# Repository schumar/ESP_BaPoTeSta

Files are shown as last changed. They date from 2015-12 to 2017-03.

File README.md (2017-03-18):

#  ESP8266 Battery Powered Temperature Station

## Moved to GitLab

This project has moved to [GitLab/schumar/ESP_BaPoTeSta](https://gitlab.com/schumar/ESP_BaPoTeSta)

## Intro

Using only an ESP8266 (no Atmel AVR) and a sensor, it's possible to build a very cheap and power-efficient WiFi-enabled weather station.

### Pictures of v0.3

BaPoTeSta Board v0.3 Rendering
BaPoTeSta Board v0.3 real

### Pictures of v0.5

BaPoTeSta Board v0.5 Rendering

### Pictures of v0.6

BaPoTeSta Board v0.6 Rendering
BaPoTeSta Board v0.6 with ATmega Rendering

### Maintenance Web-Interface

BaPoTeSta Webinterface

## Current state

I've already built 3 sensors of v0.3, and around 60 of v0.5.  
Right now I'm working on a major redesign of the board, and improving the firmware.

The sensors are reporting their data via MQTT, so the data can be received with [OpenHAB](http://www.openhab.org/),
[FHEM](http://fhem.de/fhem.html) or a small Perl script.

"Release early, release often" -- so don't expect to be able to clone this repo and have a working IoThingy 10 minutes later :)

## Screenshot

RRD Graph

## Technical details

-> Read the source, stare at my KiCAD schematic :)

## BOM

Quick calculation: 1 board would cost ca. 4.81 to 7.50 USD (excl. batteries),
depending on which sensors you want. (Calculation for an order of 30 boards)

Part|Need/Board|URL|per piece|per board
----|---------:|---|----------:|----------:|
PCB|1|http://dev.dangerousprototypes.com/store/pcbs|0.50|0.50
PinHdr|11|http://www.aliexpress.com/item/x/32537378399.html|0.01|0.09
1uF 1206|2|http://www.aliexpress.com/store/1361740|0.03|0.06
10uF|1|http://www.aliexpress.com/item/x/32260294384.html|0.07|0.07
ESP8266|1|http://www.aliexpress.com/item/x/32519328481.html|1.93|1.93
10k 1206|10|http://www.aliexpress.com/item/x/32569352008.html|0.01|0.09
56k 1206|1|http://www.aliexpress.com/item/x/32567865953.html|0.02|0.02
MCP1700|1|http://www.aliexpress.com/item/x/32523953207.html|0.36|0.36
BatteryCase|1|http://www.aliexpress.com/item/x/2022527017.html|1.06|1.06
**Sub-Total**||||**4.18**
DS18B20|1|http://www.aliexpress.com/item/x/32576213069.html|0.63|0.63
DHT22|1|http://www.aliexpress.com/item/x/32544057083.html|2.70|2.70
**Only DS18B20**||||**4.81**
**Only DHT22**||||**6.87**
**Both**||||**7.50**

## To Do

see [Issues](https://gitlab.com/schumar/ESP_BaPoTeSta/issues)

## Thanks

* Many thanks to all the people working on the [Arduino core for ESP8266](https://github.com/esp8266/Arduino)
* Cheers to [jdunmire](https://github.com/jdunmire/kicad-ESP8266) for his ESP8266 KiCAD library!

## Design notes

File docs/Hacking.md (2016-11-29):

# Hacking

## Install Arduino

Get Arduino from https://www.arduino.cc/en/Main/Software

## Add ESP8266 to Arduino

Start the Arduino IDE, go to File/Preferences, and add the following line to "Additional Boards Manager URLs:"
 http://arduino.esp8266.com/stable/package_esp8266com_index.json

Go to Tools/Board: "something"/Boards Manager...
Search for "esp82", click on the "esp8266 by ESP Community", click Install

(for details, see https://github.com/esp8266/Arduino)

## Add required libraries

In Sketch/Include Library, Manage Libraries...
Install "DallasTemperature", "DHT sensor library" and "PubSubClient".

## Clone this repository

cd ~/Arduino
git clone --recursive https://github.com/schumar/ESP_BaPoTeSta.git

## Start coding

Open the ESP_BaPoTeSta project in Arduino, and hack away

## Upload

### Connect a Serial-to-USB adapter to your board

Switch off your board.
Ensure that your adapter is set to 3.3V!
Connect the "GND" pin of the adapter to the "GND" pin of the ESP.
Connect the "TX" pin of the adapter to the "RX" pin of the ESP, and vice versa.
Do *not* connect VCC, unless you know what you are doing!

### Connect to your PC

I guess you can figure out how to do this :)

### Transfer firmware

Put a jumper bridge on the 2 "Upload" pins.
Press Ctrl+U in Arduino (or click the "Play" button)
While the sketch is compiling, switch on the board.

If it doesn't work the first time, make sure that the correct serial port is
selected in Tools/Port, and try again.

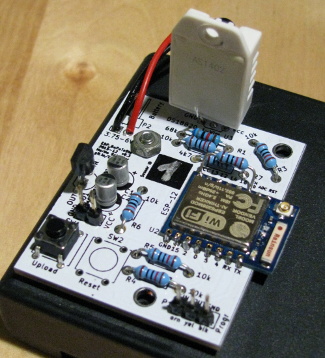
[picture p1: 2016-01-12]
docs/board_v0.3_real.jpg

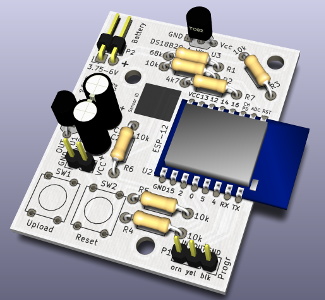
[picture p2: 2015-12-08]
docs/ESP_BaPoTeSta.jpg

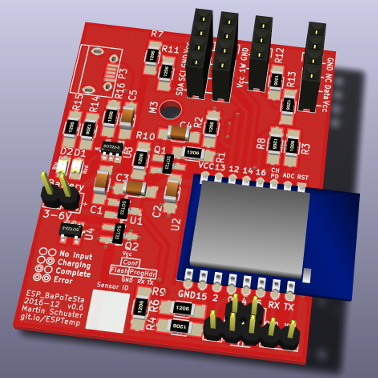
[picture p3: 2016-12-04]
docs/board_v0.6_render.jpg

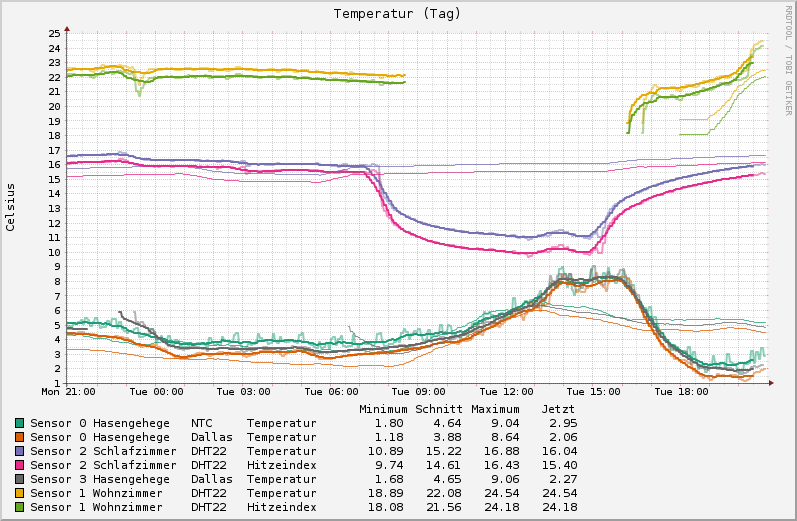
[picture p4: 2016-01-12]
docs/temp-daily.png

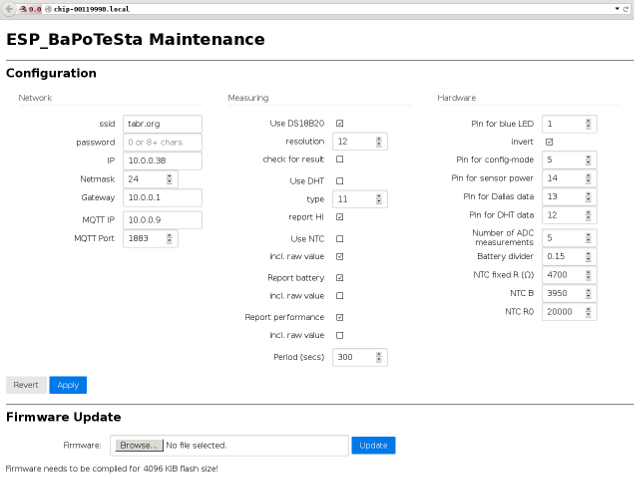
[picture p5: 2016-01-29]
docs/webinterface.png

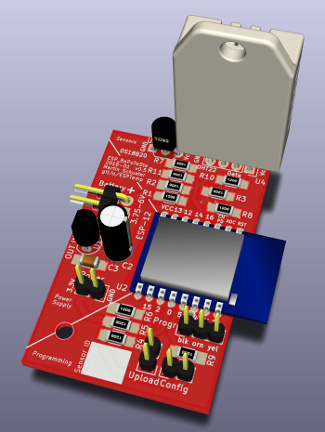
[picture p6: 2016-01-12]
docs/board_v0.5_render.jpg

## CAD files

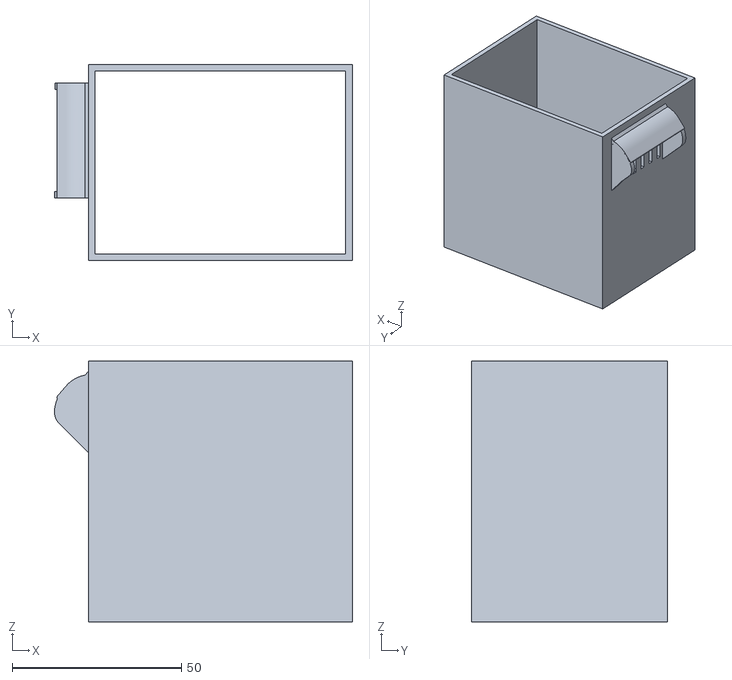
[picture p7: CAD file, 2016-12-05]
3d.printable.cases/outdoor.case/case-middle.stl
88.0 x 58.0 x 77.0

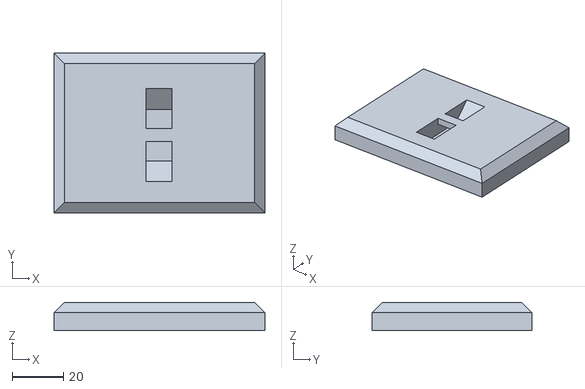
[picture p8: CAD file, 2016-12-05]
3d.printable.cases/outdoor.case/case_top.stl
82.0 x 62.0 x 11.0

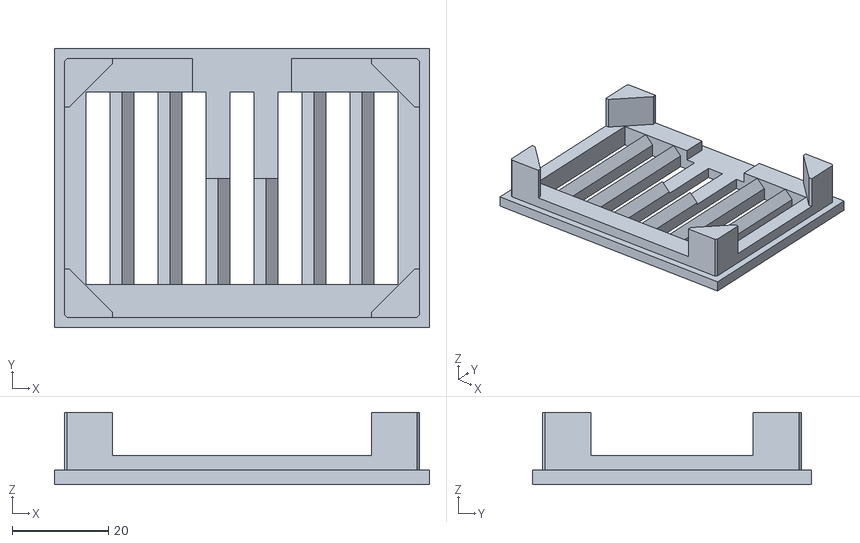
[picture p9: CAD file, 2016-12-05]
3d.printable.cases/outdoor.case/case_bottom.stl
78.0 x 58.0 x 15.0

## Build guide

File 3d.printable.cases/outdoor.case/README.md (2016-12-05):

#  3d printable Outdoor Case

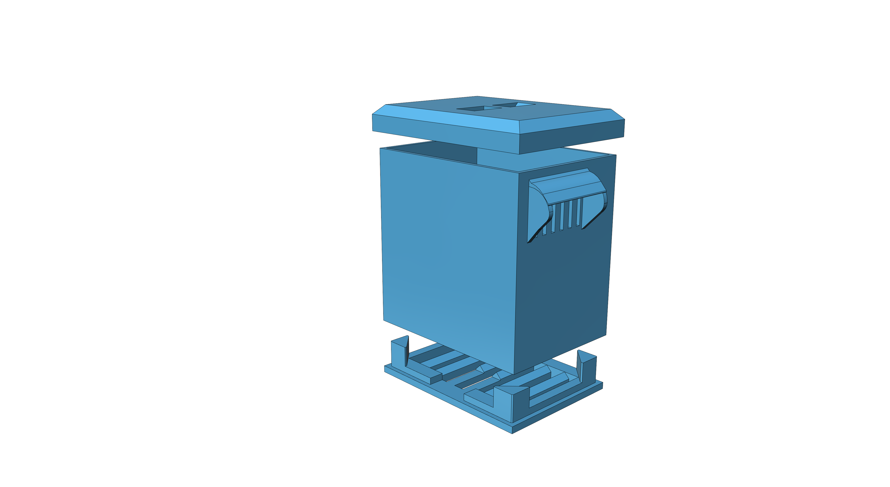
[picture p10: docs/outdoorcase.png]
Outdoor Case Rendering


Designed in 123D Design.

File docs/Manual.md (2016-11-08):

# Manual

## Read This First!

If you have acquired a finished BaPoTesTa, you can skip ahead to
(Configuration)[#configuration] now!

The following instructions are for the board as I designed it -- if you are
using another PCB, or have modified the schematics, they might still be a good
rough guideline.

If you want to attach other sensors, actuators, MOSFETs or whatever: There is
one unused pin (GPIO 4) which even has a through-hole you can solder a wire
into, and on the bottom of the board there are 2 solder bridges for GPIO 12
and GPIO 13 which you can cut to use those pins (originally for the DS18B20 and
DHT22, respecticely) too.

## Parts List

### Basic parts

* 1 PCB
* 10 SMD (1206) 10k&Omega; resistors
* 1 SMD (1206) 56k&Omega; resistor
* 2 SMD (1206) 1&mu;F capacitors
* 1 MCP1700 voltage regulator
* 1 100&mu;F buffer capacitor
* 1 ESP-12/12E/12F module
* 9 pin headers

### Power

You also need either either

* 1 case for 4 AA batteries
* 1 3mm screw+nut

or, if you want to plug in some other power source:

* 2 additional pin headers

### Sensors

One or both of
* 1 DS18B20 temperature sensor
* 1 DHT22 temperature&amp;humidity sensor

## Soldering

If you haven't done any soldering before (or your knowledge is a little rusty),
you might want to check the Internet for tutorials :) e.g.
* https://learn.sparkfun.com/tutorials/how-to-solder---through-hole-soldering
* https://learn.sparkfun.com/tutorials/how-to-solder---castellated-mounting-holes

but if you have some time, and want to have a good understanding of soldering,
check out
[PACE: Basic Soldering Lesson 1](https://www.youtube.com/watch?v=vIT4ra6Mo0s)  
(it's American, so prepare to snicker whenever the presenter pronounces
soldering as "soddering" :)

### Label your Board

Take a non water-solvable pen and write an ID on the white boxes on the front
and back of the board. Feel free to choose whatever scheme you want (most
people will go with "1, 2, 3,...", but why not use Klingon letters instead? ;)

### SMD Parts

Start with R1 (the only 56k&Omega; resistor, labelled "5602").  
Then do the 10k&Omega; resistors.

If you have a multi-meter, measure the resistance of R2, and the resistance
between the two left pins of R1 and R2 (R1+R2, as their right pins are
connected). Divide the first measurement (around 10k) by the second (around
66k), and note down the number (4 significant digits, i.e. "0.1534", not "0.15"
or "0.1533782")  
This will be the "battery divider" you can configure in the web-interface.

The only SMD parts left are the 2 1&mu;F capacitors (C1 and C3) -- add those.

Now is a good time to take some isopropanol, maybe mixed 1:1 with acetone,
and, using a brush, clean flux residue from the board (the ugly brown stuff).

### MCP 1700

That should be a no-brainer. Just make sure to put it in correctly (flat side
of the case points left/outward).

After soldering, cut off the 3 wires, and try to keep those short pieces, we'll
need them in the next step!

### ESP-12

I've found this to be a good way to solder the ESP-12:

* Tin the RST and GND pin of the PCB
* Put the module on the PCB
* Put 2 of the wires from the previous step through the little holes of the
  module, next to the VCC and TX pins (i.e. the corner pins which you *didn't*
  tin)
* Now heat the RST pin a little while pressing (gently!) down on the module.  
  This should fix that corner
* Do the same for GND
* Now the module is perfectly aligned and can't move anymore -- remove the 2
  wires.
* Solder all pins (do RST/GND last!)
* If you aren't an experiences solderer/ess(?), shortly heat each pin again
  (until the solder melts again), to ensure that all connections are flawless

But I'm just an amateur, so feel free to do it better! (and fork this project,
and improve this documentation ;)

This is again a good time to clean your board.

### Buffer Capacitor

This one should be easy again, just make sure that you don't swap the pins --
this is an electrolytic cap, so it has a plus- and a minus-pin, and swapping
those two can lead to Rapid Unplanned Disassembly.

### Pin Headers

Speaking from experience:
* Make sure that you count correctly! You need 3+2+2+2, and possibly 2 again
  for the power connection
* Those little bastards are really hard to separate! Using a good knife is the
  best way, but make sure not to cut yourself, and be aware that both parts will
  jump away the moment you separate them
* After soldering, those things are *hot* (d'uh). Touching them is bad
* Soldering might take a little more patience than usual, because the pins have
  a high thermal mass.

### Sensors

I've decided to use a "wide" footprint for the DS18B20, to make it easier to
solder in a cable instead of the sensor. But this means that if you want to put
the DS18B20 right on the board, you need to bend its pins a little bit. Tweezers
are quite useful for that.

While it's usually a good thing to keep pins as short as possible, I recommend
to keep the pins of the DS18B20 as *long* as possible, so the temperature
reading will be rather influenced by the air temperature than by the temperature
of the PCB.

When inserting the DHT22, make absolutely sure that the grill points outwards!

### Mounting Screw

Now is a good time to prepare a hole where the mounting screw will go through,
e.g. if you plan to put the board directly on a battery case, drill a hole
in that.

The antenna of the ESP-12 module (at the right border of the board) shouldn't
be covered by metal, if possible!

### Power

If you want to plug the power supply onto the board, solder in 2 pin headers.

Otherwise, solder the cables directly in the two pins. There are 2 small
mounting holes just left of the pins, which you can put the cables through (to
protect the solder joints from tension).

### Finish

Make one last visual inspection of all soldering joints.

If you want, you can switch on your board now -- it should briefly flash the
blue LED on the module. If the LED doesn't flash, switch off the board, take
your multimeter and test all connections :(  
If it does flash, switch the board off again; no use in wasting energy.

Tin, clean, re-tin you soldering iron, switch it off, clean the board, put back
any unused parts. Wash your hands if you aren't using lead-free solder!

Congratulations :)  
You are now ready to flash the firmware!

## Flashing

Right now, your ESP-12 has the stock firmware, which is useless for what we want
to do.

### Firmware

If you want to compile the firmware yourself, see the [Hacking doc](Hacking.md)
on how to do this.

But there are only a few reason to do so:

* Your ESP8266-module has a flash size other than 4MiB
* You have modified the board (or using a completely different one), and can't
  use GPIO 5 for entering the Maintenance mode
* While you can change the WiFi-password for the Maintenance mode directly in
  the Maintenance web-interface, the board will still start with the default
  password the first time. If you are worried about that, you are even more
  paranoid than me :)
* You don't trust binaries you haven't compiled yourself -- good for you!

Otherwise, just take the [precompiled firmware](../precompiled/).

### Connect a Serial-to-USB adapter to your board

You need a Serial-to-USB adapter with support for 3.3V levels instead
of 5V, e.g. [FTL232](XXX)

* Switch off your board.
* Ensure that your adapter is set to 3.3V!
* Connect the "GND" pin of the adapter to the "GND" pin of the ESP.
* Connect the "TX" pin of the adapter to the "RX" pin of the ESP, and vice versa.
  Do *not* connect VCC, unless you know what you are doing!

### Connect the adapter to your PC

I guess you can figure out how to do this :)

Check dmesg for the device name of the adapter (e.g. /dev/ttyUSB0)

### Transfer firmware

You will also need the [esptool](XXX), and of course 
* Put a jumper bridge on the 2 "Upload" pins.
* Type the command
  esptool -vv -cd ck -cb 115200 -cp /dev/ttyUSB0 -ca 0x00000 -cf ESP_BaPoTeSta.ino.bin
  but don't press enter yet
* Switch on the board
* Press Enter

If it doesn't work the first time, make sure that you have specified the correct
device name, and that you haven't swapped TX and RX. Try again.

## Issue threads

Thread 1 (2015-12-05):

[arduino] Add support for 1-wire sensors

schumar, 2015-12-05:
RIght now the code only supports an NTC as temperature-sensor.
Support 1-wire sensors (DS18B20, DHT11, DHT22,...) too

schumar, 2016-01-05:
DHT22 is not a 1Wire-device. ouch.
So commit:e0159d8 closes this issue.

Closed 2016-01-05.

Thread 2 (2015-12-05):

[arduino] add more power-saving measures

schumar, 2015-12-05:
* switch off UART
* put all unused pins into INPUT/OUTPUT/?
* (read ESP8266 data-sheet, search web)

schumar, 2016-01-09:
The current board needs around 500uA in sleep, that's half a year running on 2000mAh-batteries.
This is completely negligible compared to the ca. 100mA when the chip is "on".

Closed 2016-01-09.

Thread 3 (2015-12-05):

[arduino] timestamp values

schumar, 2015-12-05:
Right now, we only send a single value (temperature); add the current timestamp.

This needs NTP, and we don't want to do an NTP-query every time we wake up, so: EEPROM.

clever plan (taken from my comments in the source):
<pre>
        read time + counter from eprom
        if 0, or counter > 100(?)
            retrieve time via NTP
            reset counter
            write new time to eprom
        when sending data, use time + counter * (SLEEPSEC + c)
            c needs to be calibrated (few secs)
        write counter to eprom
</pre>

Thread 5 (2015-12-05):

[pcb] move "Values" to silk-screen

schumar, 2015-12-05:
Looks like I have to manually `s/F.Fab/F.SilkS/` in the pcb file, according to [this KiCAD forum post](https://forum.kicad.info/t/join-silkscreen-layers/1456/3), and the friendly guys on #kicad@freenode

Closed 2015-12-06.

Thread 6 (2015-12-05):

[pcb] add test points

schumar, 2015-12-05:
GND, VCC, 1Wire

schumar, 2016-01-09:
There's already a pin-header for Vcc/GND, everything else is easily accessible on the board :)

Closed 2016-01-09.

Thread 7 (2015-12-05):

[pcb] label ProgHdr

schumar, 2015-12-05:
Label the ProgHdr pins "RXI/Org" and "TXO/Red" (or was it the other way round? check first!), and "GND/blk"
BattHdr "+"/"-"
...

schumar, 2015-12-06:
fixed in commit/583a656

Closed 2015-12-06.

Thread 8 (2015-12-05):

[pcb] add BOM

schumar, 2015-12-05:
Add a nice BOM (maybe include it in the README), ideally with links to aliexpress or dx

schumar, 2015-12-06:
commit/583a656 fixes #7, not #8 *sigh*

Closed 2015-12-06.

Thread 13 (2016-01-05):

[arduino] support DHT22

schumar, 2016-01-05:
New issue, as #1 only handled 1-Wire sensors

Closed 2016-01-05.

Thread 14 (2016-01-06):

[pcb] MCP1700 pins wrong

schumar, 2016-01-06:
Pins of MCP1700 are GND-In-Out, not In-GND-Out

Closed 2016-01-09.

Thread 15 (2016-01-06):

[pcb] Reset-button attached to wrong pin

schumar, 2016-01-06:
For unknown reasons, I have attached the button "Reset" to GPIO15 instead of the RST pin

Closed 2016-01-09.

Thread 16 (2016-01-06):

[pcb] Wake-up doesn't work

schumar, 2016-01-06:
I've connected pin CH_PD instead of GPIO16 to RST

Closed 2016-01-09.

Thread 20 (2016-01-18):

[arduino] implement correction offset

schumar, 2016-01-18:
Allow user to specify an offset for each sensor/measurement, e.g. "-0.1" would mean "report 0.1 less than what the sensor measured".

schumar, 2016-04-20:
implemented in 1ab810149525a7f45dca42e1722ebf7dc1ef25d9

Closed 2016-04-20.

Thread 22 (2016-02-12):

[pcb] SMD-pins connected to GND-plane are hard to solder

schumar, 2016-02-12:

florianschmidt, 2016-02-19:
Sorry to say but I can't reproduce this. Also the GND-plane connected SMD-pins where easy to solder

Closed 2016-12-03.

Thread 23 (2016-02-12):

[pcb] make UART1 usable

schumar, 2016-02-12:
ESP8266 has a second UART, UART1, for debugging (TX-only, on GPIO2)
Think about some way of making it usable

schumar, 2016-12-03:
As GPIO2 is now "abused" for the data line of the DHT22, it is accessible already.

Closed 2016-12-03.

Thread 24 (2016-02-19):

100μF buffer capacitor to SMD?

florianschmidt, 2016-02-19:
Check possible SMD capacitors

mer-at, 2016-04-20:
those look quite cheap
http://tinyurl.com/jxrbo84

1206 SMD capacitor 100uf
50 pieces for 4,16$ including shipping

mer-at, 2016-04-20:
LP 2985 IM5-3,3 might be a good replacement for the voltage regulator?
1.0uA instead of 1.6uA standby current.
16V supply voltage instead of just 6V (4 normal AA Batteries already give me 6,57V)
reichelt got them for 47cent a piece

can be used with small ceramic capacitor as output cap.

schumar, 2016-04-22:
The LP2985 is only rated for 150mA; but LP38691DT-3.3 looks interesting

schumar, 2016-11-29:
Created #33 for the voltage regulator topic.

Closed 2016-11-30.

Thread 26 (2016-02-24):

[src] confg mode SSID/PW doesn't get set

schumar, 2016-02-24:
uses ESP_[sernr] as SSID, and no PW

schumar, 2016-04-20:
Looks like this was caused by a bad Arduino (IDE) setup, can't reproduce

Closed 2016-04-20.

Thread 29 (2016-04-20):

[pcb] avoid 90deg-corners

schumar, 2016-04-20:
We shouldn't use 90deg-bends in traces, [according to Pete](https://www.youtube.com/watch?v=NJKZZArjdg8)

Closed 2016-11-29.

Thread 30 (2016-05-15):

[pcb] Electrolytic buffer cap wastes energy

schumar, 2016-05-15:
Might have significant leak current.
Thanks @MalteP!

schumar, 2016-11-29:
Also see #24

Closed 2016-11-30.

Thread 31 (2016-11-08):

[pcb] check trace widths

schumar, 2016-11-08:
According to http://circuitcalculator.com/wordpress/2006/01/31/pcb-trace-width-calculator/
a 5mil-trace at 200mA will only heat up by 1degC, and lose 19mV/inch

schumar, 2016-12-04:
"Saturn PCB Design Toolkit" https://www.saturnpcb.com/pcb_toolkit.htm
agrees, as does http://www.desmith.net/NMdS/Electronics/TraceWidth.html

Closed 2016-12-04.

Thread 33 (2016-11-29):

Investigate other voltage regulators

schumar, 2016-11-29:
People might want to use higher or lower input voltages.

LP38691DT-3.3 might be a good candidate (up to 10V, and dropout of only .25V, this would allow a range of 2.75-10V instead of the 3-6V we need now). 55uA quiescent current is quite high, though.

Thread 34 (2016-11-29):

Support replacing the ESP12 with an ATmega

schumar, 2016-11-29:
It should be possible to add the footprint of an ATmega328P-AU (TQFP, 7x7mm, 0.8mm pitch) within the ESP12-footprint.

random thoughts:
* lower standby current (0.9uA in "powersave" mode of AVR)
* no WiFi anymore
* ...so additional pins for controlling some 433MHz-thingy needed
* code needs to be able to handle both ICs
* "config" only via flashing new firmware
* traces below the ESP might act as little antennas
* could use internal oscillator, I2C/1Wire/DHT should be able to handle slight timing variations

schumar, 2016-12-04:
For the 433MHz-communication, use the RadioHead library,
http://www.airspayce.com/mikem/arduino/RadioHead/index.html

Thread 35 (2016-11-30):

[pcb] reverse leakage of battery charger?

schumar, 2016-11-30:
If no voltage is supplied via USB, will there be leakage current from the battery through the charger IC?
If so, this needs to be blocked (via MOSFET)

schumar, 2016-12-03:
0.25uA for floating Vdd according to datasheet, safe to ignore

Closed 2016-12-03.

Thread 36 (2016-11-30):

[pcb] Protect battery against under-voltage

schumar, 2016-11-30:
Right now, we will drain the poor battery until it's dead :cry:

schumar, 2016-11-30:
Of course, users can still use a battery which contains a protection-PCB, but that sounds like a waste of money

schumar, 2016-12-01:
Replacing the current charge controller with an MCP73871 would help (that chip sounds great), but it only comes in a QFN20 package, which is really tricky to solder by hand

schumar, 2016-12-03:
Switch a MOSFET through an undervoltage sensor like
http://www.onsemi.com/pub/Collateral/NCP300-D.PDF
?

Closed 2016-12-03.

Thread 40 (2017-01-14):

[pcb] on/off-switch

schumar, 2017-01-14:
...so the user can stop measuring while charging the battery (that will most likely happen at another place than the usual measurements, and thus introduce useless data)

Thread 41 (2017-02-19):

[pcb] MCP1700 wrong pinout

schumar, 2017-02-19:
The currently used pin-out (1=GND, 2=In, 3=Out) is only correct for the TO-92 and SOT-89 packages of this chip; the SOT-23 version has 1=GND, 2=Out, 3=In

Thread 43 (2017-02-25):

[pcb] battery measurement doesn't work

schumar, 2017-02-25:
I've used Malte's circuit with the MOSFET, completely ignoring the fact that he uses LOW to switch it on, while my setup sets PwrSens to HIGH while measuring :(

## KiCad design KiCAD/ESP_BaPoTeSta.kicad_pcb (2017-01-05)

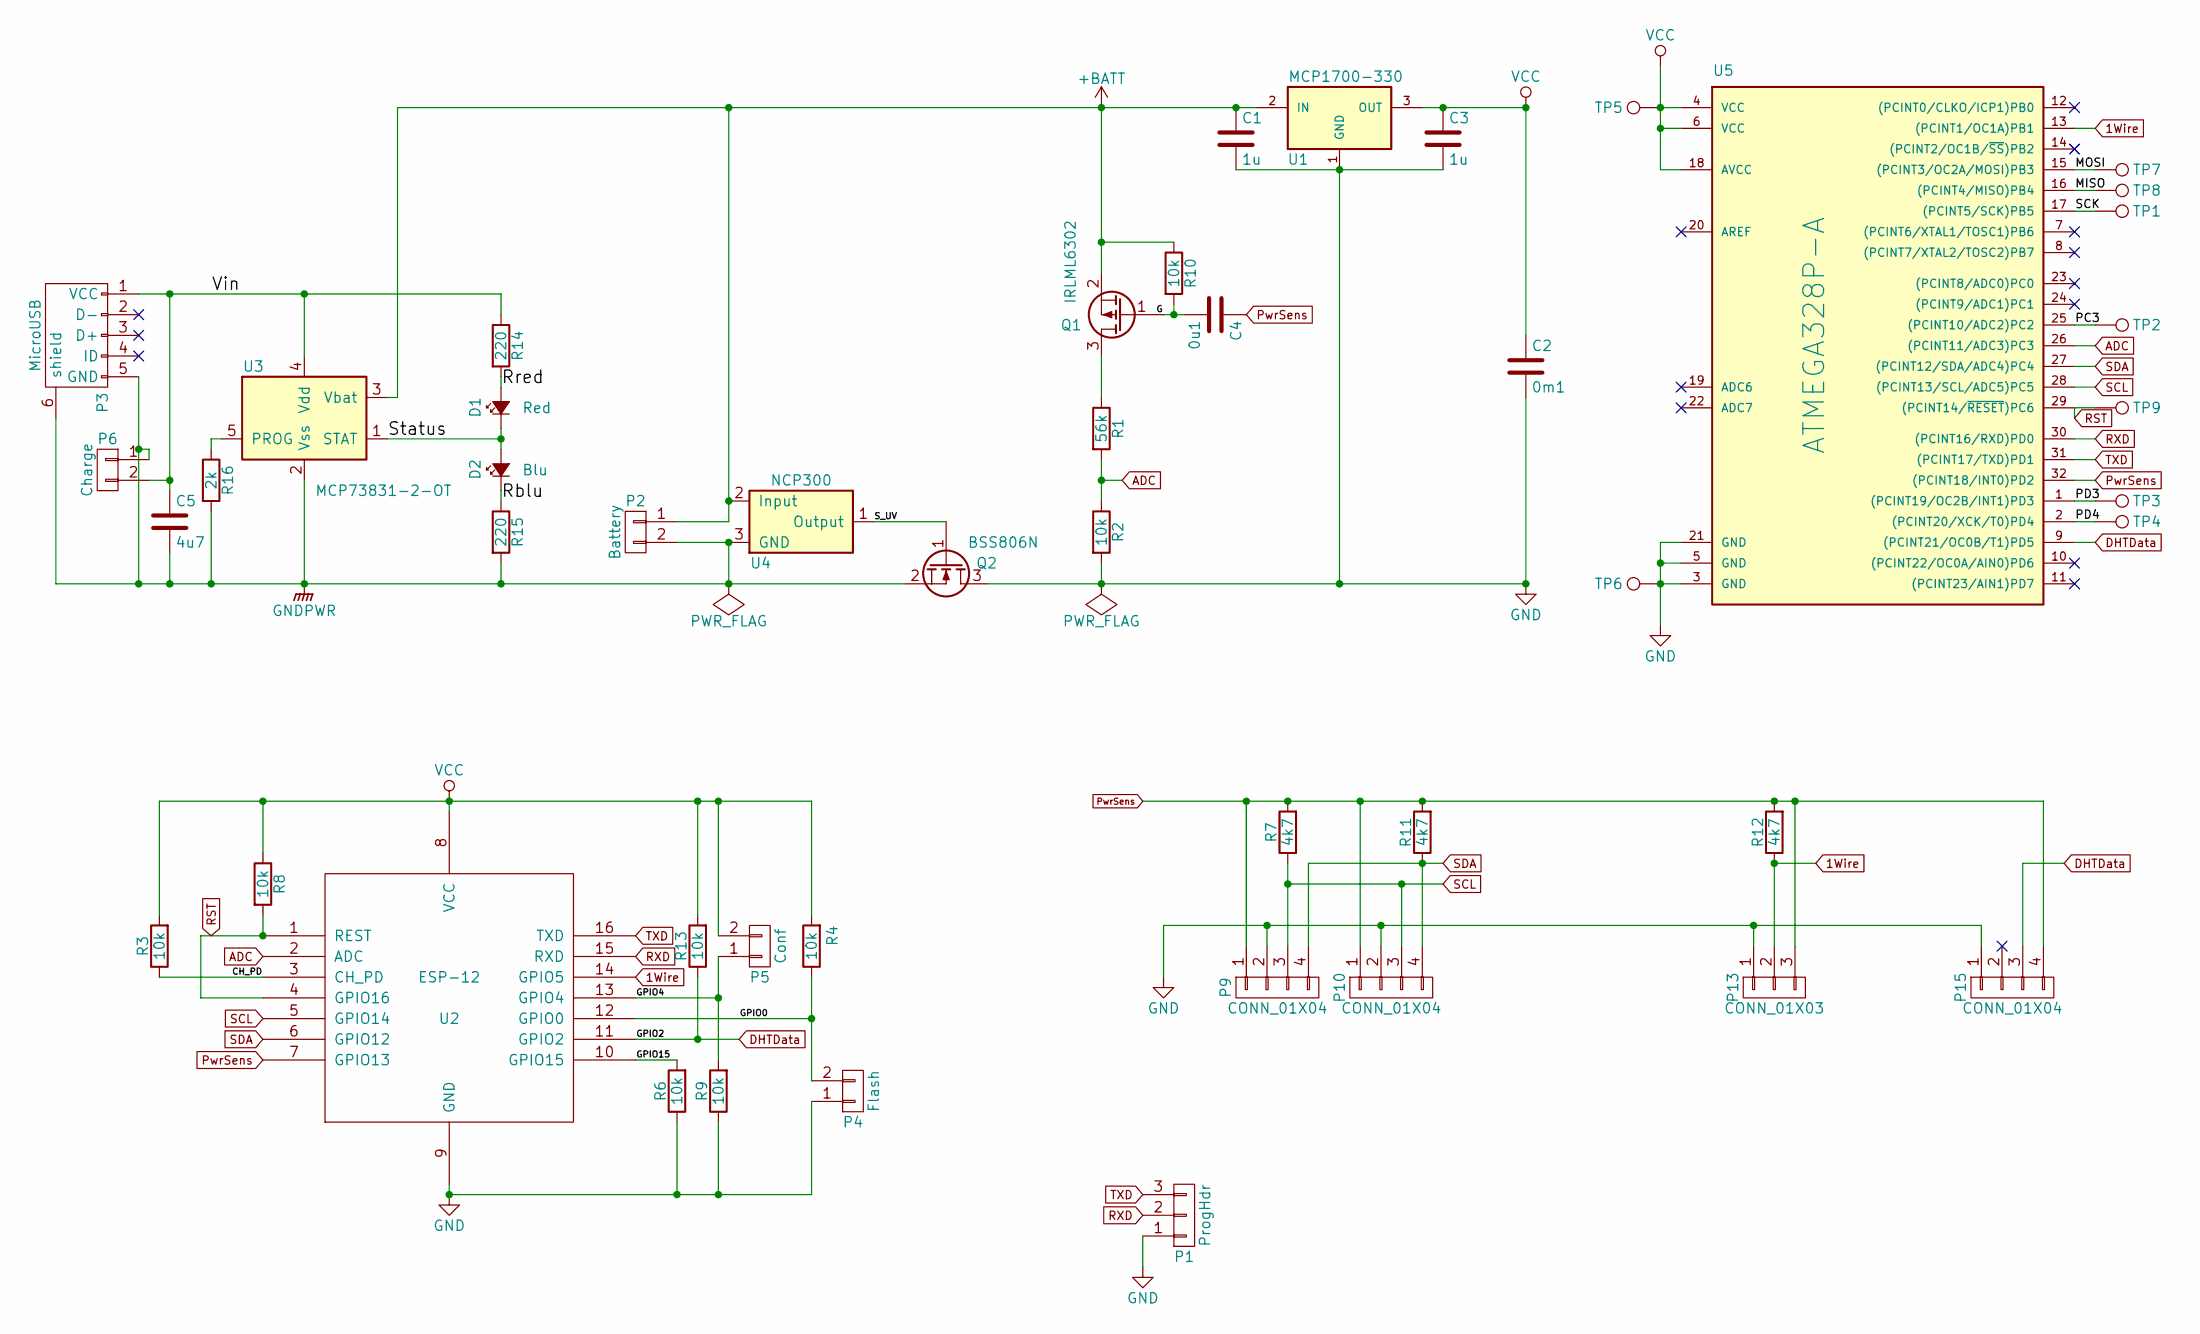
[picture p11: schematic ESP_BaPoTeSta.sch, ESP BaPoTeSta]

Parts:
C1, C3: 1u; C_1206_HandSoldering
C2: 0m1; C_1206_HandSoldering
C4: 0u1; C_1206_HandSoldering
C5: 4u7; C_1206_HandSoldering
D1: Red; LED_0805
D2: Blu; LED_0805
P1: ProgHdr; Pin_Header_Straight_1x03
P2: Battery; Pin_Header_Straight_1x02
P3: MicroUSB; USB_Micro-B
P4: Flash; Pin_Header_Straight_1x02
P5: Conf; Pin_Header_Straight_1x02
P6: Charge; Pin_Header_Straight_1x02
P9, P10, P15: CONN_01X04; Socket_Strip_Straight_1x04
P13: CONN_01X03; Socket_Strip_Straight_1x03
Q1: IRLML6302; SOT-23_Handsoldering
Q2: BSS806N; SOT-23_Handsoldering
R1: 56k; R_1206_HandSoldering
R2, R3, R4, R6, R8, R9, R10, R13: 10k; R_1206_HandSoldering
R7, R11, R12: 4k7; R_1206_HandSoldering
R14, R15: 220; R_1206_HandSoldering
R16: 2k; R_1206_HandSoldering
TP1, TP2, TP3, TP4, TP5, TP6, TP7, TP9: TEST_1P; Measurement_Point_Square-SMD-Pad_Small
TP8: TEST_1P; Measurement_Point_Round-SMD-Pad_Small
U1: MCP1700-330; SOT-23_Handsoldering
U2: ESP-12
U3: MCP73831-2-OT; SOT-23-5
U4: NCP300; SOT-23-5
U5: ATMEGA328P-A; TQFP-32_7x7mm_Pitch0.8mm

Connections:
1Wire: P13.2, R12.1, U2.14 (GPIO5), U5.13 ((PCINT1/OC1A)PB1)
+BATT: C1.1, P2.1, Q1.2 (S), R10.1, U1.2 (IN), U3.3 (Vbat), U4.2 (Input)
/CH_PD: R3.1, U2.3 (CH_PD)
/G: C4.2, Q1.1 (G), R10.2
/GPIO0: P4.2, R4.1, U2.12 (GPIO0)
/GPIO4: P5.1, R9.2, U2.13 (GPIO4)
/GPIO15: R6.2, U2.10 (GPIO15)
/MISO: TP8.1, U5.16 ((PCINT4/MISO)PB4)
/MOSI: TP7.1, U5.15 ((PCINT3/OC2A/MOSI)PB3)
/PC3: TP2.1, U5.25 ((PCINT10/ADC2)PC2)
/PD3: TP3.1, U5.1 ((PCINT19/OC2B/INT1)PD3)
/Rblu: D2.1 (K), R15.1
/Rred: D1.2 (A), R14.2
/SCK: TP1.1, U5.17 ((PCINT5/SCK)PB5)
/S_UV: Q2.1 (G), U4.1 (Output)
/Status: D1.1 (K), D2.2 (A), U3.1 (STAT)
/Vin: C5.1, P3.1 (VCC), P6.2, R14.1, U3.4 (Vdd)
ADC: R1.2, R2.1, U2.2 (ADC), U5.26 ((PCINT11/ADC3)PC3)
DHTData: P15.3, R13.1, U2.11 (GPIO2), U5.9 ((PCINT21/OC0B/T1)PD5)
GNDPWR: C5.2, P2.2, P3.5 (GND), P3.6 (shield), P6.1, Q2.2 (S), R15.2, R16.2, U3.2 (Vss), U4.3 (GND)
unnamed: Q1.3 (D), R1.1
unnamed: R16.1, U3.5 (PROG)
PwrSens: C4.1, P9.1, P10.1, P13.3, P15.4, R7.2, R11.2, R12.2, U2.7 (GPIO13), U5.32 ((PCINT18/INT0)PD2)
RST: R8.2, TP9.1, U2.1 (REST), U2.4 (GPIO16), U5.29 ((PCINT14/~RESET~)PC6)
RXD: P1.2, U2.15 (RXD), U5.30 ((PCINT16/RXD)PD0)
SCL: P9.3, P10.3, R7.1, U2.5 (GPIO14), U5.28 ((PCINT13/SCL/ADC5)PC5)
SDA: P9.4, P10.4, R11.1, U2.6 (GPIO12), U5.27 ((PCINT12/SDA/ADC4)PC4)
TXD: P1.3, U2.16 (TXD), U5.31 ((PCINT17/TXD)PD1)
VCC: C2.1, C3.1, P5.2, R3.2, R4.2, R8.1, R13.2, TP5.1, U1.3 (OUT), U2.8 (VCC), U5.4 (VCC), U5.6 (VCC), U5.18 (AVCC)

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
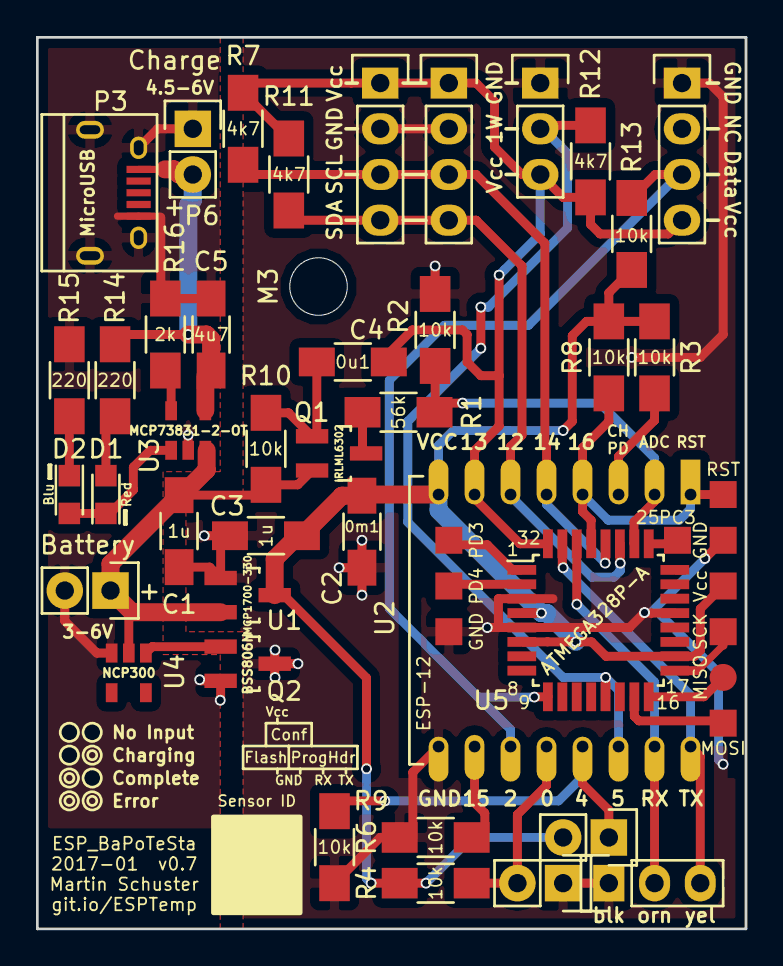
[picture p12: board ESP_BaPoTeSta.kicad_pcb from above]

Board: 2 copper layers, 39.4 x 49.5 mm, 50 parts (0 on the bottom side), 31 nets.

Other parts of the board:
M3: MountingHole_3.2mm_M3_ISO7380
TP4#2: TEST_1P; Measurement_Point_Square-SMD-Pad_Small

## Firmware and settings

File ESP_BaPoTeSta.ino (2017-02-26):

/*
   ESP8266 Battery Powered Temperature Station
   https://git.io/ESPTemp

   Martin Schuster 2015 - 2016
 */

#include <ESP8266WiFi.h>
#include <WiFiUdp.h>
#include <math.h>
#include <OneWire.h>
#include <DallasTemperature.h>
#include <DHT.h>
#include <PubSubClient.h>
#include <ESP8266WebServer.h>
#include <ESP8266mDNS.h>
#include <ESP8266HTTPUpdateServer.h>
#include <EEPROM.h>
#include <Wire.h>
#include <Adafruit_Sensor.h>
#include <Adafruit_BMP280.h>

#ifdef SERIALDEBUG
#include <Serial.h>
#endif

#include "config.h"
#include "ESP_BaPoTeSta.h"

// globals
struct sensorMeasurement sensorMeasurements[maxSensors];
struct allMeasurements data;
struct config config;
WiFiClient espClient;
PubSubClient mqttClient(espClient);
OneWire oneWire(0xff);
DallasTemperature dallasSensors(&oneWire);
DHT dhtSensor(0,0);
bool configmode = false;
ESP8266WebServer httpServer(80);
IPAddress IPSubnet(255, 255, 255, 0);

Adafruit_BMP280 bmp280;

#ifdef SERIALDEBUG
ESP8266HTTPUpdateServer httpUpdater(true);
#else
ESP8266HTTPUpdateServer httpUpdater;
#endif


void setup() {
    // activate (active low) blue LED to show that we are "on"
    if (config.pinblue >= 0) {
        pinMode(config.pinblue, OUTPUT);
        digitalWrite(config.pinblue, config.invblue ? LOW : HIGH);
    }

    #ifdef SERIALDEBUG
    Serial.begin(230400);
    delay(10);
    debugPrint("\nSYNCSYNC\n");
    #endif

    EEPROM.begin(1024);
    getConfig();

    // check if "config mode" jumper is set
    if (digitalRead(config.pinconfig)) {
        debugPrint("Starting webserver");

        configmode = true;
        setupWebserver();

    } else {
        debugPrint("Starting normally");

        configmode = false;
        setupNormal();
    }
}

void setupNormal() {
    char idBuffer[32];

    // start WiFi
    debugPrint("Connecting to WiFi...");
    WiFi.mode(WIFI_STA);
    WiFi.config(config.ip, config.gw, IPSubnet);
    if (config.password == NULL || config.password[0] == 0) {
        WiFi.begin(config.ssid);
    } else {
        WiFi.begin(config.ssid, config.password);
    }

    // now is a perfect time for "other" stuff, as WiFi will need some time
    // to associate

    // get ChipID, will be used as unique ID when sending data
    data.chipId = ESP.getChipId();
    data.sensorMeasurements = sensorMeasurements;
    data.nrMeasurements = 0;

    if (config.battery) getBattery();

    powerSensors(true);     // activate power to sensors

    // setup Dallas sensors
    if (config.usedallas) {
        oneWire = OneWire(config.pindallas);
        dallasSensors.begin();
        dallasSensors.setResolution(config.dallasres);
        dallasSensors.setCheckForConversion(config.dallaswait);
    }

    // setup DHT sensor
    if (config.usedht) {
        dhtSensor = DHT(config.pindhtdata, config.dhttype);
        dhtSensor.begin();
    }

    // setup I2C
    if (config.usebmp280) {
        Wire.begin(config.pini2csda, config.pini2cscl);
    }

    // setup BMP280
    if (config.usebmp280) {
        // if bmp280addr is set, use it, otherwise stick to the default (0x77)
        if (! (config.bmp280addr > 0 ?
                    bmp280.begin(config.bmp280addr) : bmp280.begin())) {
            debugPrint("BMP280 not found.");
        }
    }

    // wait until WiFi is connected, but max maxConnRetry
    for (byte i = 0;
            i < maxConnRetry && WiFi.status() != WL_CONNECTED;
            i++)
        delay(sleepWifiCheck);
    // if this didn't work, go back to sleep
    if (WiFi.status() != WL_CONNECTED)
        gotoSleep(noConnSleepSec);

    debugPrint("Connected to WiFi.");

    // connect to MQTT server
    mqttClient.setServer(config.mqttip, config.mqttport);
    sprintf(idBuffer, "esp8266-%08lx", data.chipId);
    mqttClient.connect(idBuffer);
    debugPrint("Connected to MQTT server.");

}


void loop() {
    if (configmode) {
        httpServer.handleClient();
        delay(1);
    } else {
        // this won't actually "loop", as the last command leads to a reset
        data.timestep = 0;      // [XXX] this needs to be read from eprom and ++

        mqttClient.loop();

        collectData();          // make measurements
        powerSensors(false);    // deactivate power to sensors again

        sendData();
        mqttClient.loop();

        // wait a little bit, to ensure that everything is sent
        delay(sleepEnd);
        mqttClient.loop();
        gotoSleep(config.deltat);
    }
}

void collectData() {
    debugPrint("Collecting data...");
    if (config.usedallas) getDallas();
    if (config.usebmp280) getBMP280();
    if (config.usedht) getDHT();
    if (config.dowifi) getWiFi();
    if (config.doperf) getPerf();
}

void getDallas() {
    uint8_t addr[8];
    float temp;
    uint16_t id;

    debugPrint("Searching for DS18B20");

    // try to find address of first sensor
    if (dallasSensors.getAddress(addr, 0) == 0) return;

    dallasSensors.requestTemperaturesByAddress(addr);
    temp = dallasSensors.getTempC(addr);

    debugPrint("DSTmp=" + (String)temp);

    // sanity check; valid range taken from datasheet
    // "85" is the "reset value", ignore it too
    if (temp < -55.0 || temp > 125.0 || (temp > 84.95 && temp < 85.05))
        return;

    // add the bias after checking for "85" above
    temp += config.biasDallasTemp;

    if (DALLAS_ID > 0) {
        id = DALLAS_ID;
    } else {
        id = (addr[2]<<8) + addr[1];
    }

    // use last two byte of serial as ID (addr[0] is "family code")
    addData(id, TEMP, (int) (temp * 100.0), CENT_DEGC);
}

void getBMP280() {
    float temp;
    float pres;

    debugPrint("Querying BMP280...");

    temp = bmp280.readTemperature();
    pres = bmp280.readPressure();

    debugPrint("BMP280Temp=" + (String)temp + "\n" +
               "BMP280Pres=" + (String)pres);

    if (pres < 1.0)
        return;

    addData(0x0280, TEMP, (int) (temp * 100.0), CENT_DEGC);

    if (config.bmppress) {
        // report measured pressure (current height)
        addData(0x0280, PRESSURE, (int) (pres), PASCAL);
    }
    if (config.bmpslp && config.heightASL > 0) {
        // report pressure at sea level
        addData(0x0280, PRESSUREASL, (int) (sealevelPressure(pres)), PASCAL);
    }
}

void getDHT() {
    delay(sleepDHT);    // [XXX] should substract the time since power-up

    // store values, so they can be used for calculating the heat index later
    float temp = dhtSensor.readTemperature(false, true) + config.biasDHTTemp;
    float hum = dhtSensor.readHumidity() + config.biasDHTHumid;

    debugPrint("DHTHum=" + (String)hum);
    debugPrint("DHTTmp=" + (String)temp);
    // sanity check; valid range taken from datasheet
    if (temp < -40.0 || temp > 80.0 || hum < 0.0 || hum > 100.0 || isnan(temp) || isnan(hum))
        return;

    // use the DHT_TYPE as sensor ID, as the DHT doesn't have a real ID
    addData(config.dhttype, TEMP, (int) (temp * 100.0), CENT_DEGC);
    addData(config.dhttype, HUMIDITY, (int) (hum * 100.0), CENT_PERC);

    if (config.dhthi)
        addData(config.dhttype, TEMPHI,
                (int) (dhtSensor.computeHeatIndex(temp, hum, false) * 100.0),
                CENT_DEGC);
}

int readADC() {
    int sensorValue[config.adcmeas];
    char buf[16];

    // measure multiple times
    for (byte c=0; c<config.adcmeas; c++) {
        delay(sleepADCmeasure);
        sensorValue[c] = analogRead(A0);
    }

#ifdef SERIALDEBUG
    for (byte c=0; c<config.adcmeas; c++) {
        sprintf(buf, "ADC %d=%d", c, sensorValue[c]);
        debugPrint(buf);
    }
#endif

    // calculate median
    bubbleSort(sensorValue, config.adcmeas);

    // as config.adcmeas is odd, we can just take the middle sample
    return(sensorValue[config.adcmeas/2]);
}

void getBattery() {
    int raw;
    float volt;

    pinMode(config.pinpwrsens, OUTPUT);
    digitalWrite(config.pinpwrsens, LOW);

    raw = readADC();
    volt = calcBattery(raw);

    // If battery voltage is below 3.0V, the results from most sensors will
    // be totally off -> don't even try anymore
    if (volt < VLowBat) {
        debugPrint("LOW BATTERY");
        gotoSleep(lowBattSleepSec);
    }

    addData(0, BATTERY, (int) (volt * 1000.0), MVOLT);
    if (config.battraw)
        addData(0, BATTERY, raw, RAW);
}

void getWiFi() {
    addData(0, WIFIRSSI, WiFi.RSSI(), DBM);
}

void getPerf() {
    // simply "measure" the number of CPU cycles since bootup
    unsigned long int cycles;
    cycles = ESP.getCycleCount();
    addData(0, TIME, cycles/(F_CPU/1e6), USEC);
    if (config.perfraw)
        addData(0, TIME, cycles, RAW);
}

void addData(unsigned int sensorId, enum sensorType type,
        int value, enum unitType unit) {
    byte idx = data.nrMeasurements++;
    if (idx >= maxSensors) return;

    sensorMeasurements[idx].sensorId = sensorId;
    sensorMeasurements[idx].type = type;
    sensorMeasurements[idx].value = value;
    sensorMeasurements[idx].unit = unit;
}

void sendData() {
    char payloadBuffer[16];
    char topicBuffer[128];

    for (byte i = 0; i < data.nrMeasurements; i++) {
        snprintf(topicBuffer, 128,
                "chip-%08lx/sensor-%d/%s-%s",
                data.chipId, data.sensorMeasurements[i].sensorId,
                sensorTypeName[data.sensorMeasurements[i].type],
                unitTypeName[data.sensorMeasurements[i].unit]);

        snprintf(payloadBuffer, 16,
                "%d", data.sensorMeasurements[i].value);

        mqttClient.publish(topicBuffer, payloadBuffer);
    }

}

void powerSensors(bool on) {
    // only power the pin if actually needed
    if (config.usedallas || config.usedht || config.usebmp280) {
        // when switching "off", ensure that the pin is not connected to GND or
        // Vcc anymore by changing it to INPUT
        pinMode(config.pinpwrsens, on ? OUTPUT : INPUT);
        // when pinMode is INPUT, writing LOW will disable the internal pullup
        digitalWrite(config.pinpwrsens, on ? HIGH : LOW);
    }
}


float calcBattery(int raw) {
    /*
       V = Vbatt * battDivider
       raw/1024 = V - Voff

       Vbatt = V / battDivider

     */
    return ((raw/1024. + Voff) / config.battdiv);
}

void bubbleSort(float * analogValues, int nr) {
    int out, in, swapper;
    for(out=0 ; out < nr; out++) {  // outer loop
        for(in=out; in<(nr-1); in++)  {  // inner loop
            if( analogValues[in] > analogValues[in+1] ) {   // out of order?
                // swap them:
                swapper = analogValues[in];
                analogValues [in] = analogValues[in+1];
                analogValues[in+1] = swapper;
            }
        }
    }
}

void bubbleSort(int * analogValues, int nr) {
    int out, in, swapper;
    for(out=0 ; out < nr; out++) {  // outer loop
        for(in=out; in<(nr-1); in++)  {  // inner loop
            if( analogValues[in] > analogValues[in+1] ) {   // out of order?
                // swap them:
                swapper = analogValues[in];
                analogValues [in] = analogValues[in+1];
                analogValues[in+1] = swapper;
            }
        }
    }
}

float sealevelPressure(float pressure) {
    // calculate the pressure at sea level, given the measured pressure
    // and the height it was measured at
    float slp;

    slp = pressure / (
            exp( log(1 - 1.0*config.heightASL/44330) / 0.1903 )
            );
    return slp;
}

void gotoSleep(unsigned int seconds) {

    debugPrint("Going to sleep.");

    // switch off (active low) blue LED to show that we are "off"
    if (config.pinblue >= 0) {
        digitalWrite(config.pinblue, config.invblue ? HIGH : LOW);
    }

    // go to sleep, reboot after 'seconds' seconds
    // WAKE_RF_DEFAULT, WAKE_RFCAL, WAKE_NO_RFCAL, WAKE_RF_DISABLED
    ESP.deepSleep(1e6 * seconds, WAKE_NO_RFCAL);
}

void setupWebserver() {
    char host[32];

    unsigned long int chipId = ESP.getChipId();
    sprintf(host, "chip-%08lx", chipId);

    WiFi.mode(WIFI_AP);
    char passwd[] = "bapotesta";
    WiFi.softAP(host, passwd);

    MDNS.begin(host);

    httpUpdater.setup(&httpServer);
    httpServer.on("/",  HTTP_GET, &webForm);
    httpServer.on("/style.css",  HTTP_GET, &webCSS);
    httpServer.on("/config",  HTTP_POST, &storeConfig);
    httpServer.begin();

    MDNS.addService("http", "tcp", 80);

    #ifdef SERIALDEBUG
    Serial.printf("Ready! Connect to SSID %s with password '%s'"
            " and visit http://%s.local/update\n", host, passwd, host);
    #endif
}

String ipToString (IPAddress ip) {
    const String delim = ".";
    return String(
            ip[0] + delim + ip[1] + delim + ip[2] + delim + ip[3]
            );
}

IPAddress stringToIP (String text) {
    byte octet[4];
    byte pos = 0;

    for (byte i = 0; i < 4; i++) {
        byte dot = text.indexOf('.', pos);
        octet[i] = text.substring(pos, dot).toInt();
        pos = dot + 1;
    }

    return IPAddress(octet[0], octet[1], octet[2], octet[3]);
}

void webForm() {
    // called when client does a  GET /
    String buf;

    buf = indexPage;
    buf.replace("${flashsize}", String(ESP.getFlashChipRealSize()/1024));
    buf.replace("${buildtime}", String(__DATE__ + String(" at ") + __TIME__));

    buf.replace("${ssid}", String(config.ssid));
    buf.replace("${password}", String(config.password));
    buf.replace("${ip}", ipToString(config.ip));
    buf.replace("${netmask}", String(config.netmask));
    buf.replace("${gw}", ipToString(config.gw));
    buf.replace("${mqttip}", ipToString(config.mqttip));
    buf.replace("${mqttport}", String(config.mqttport));

    buf.replace("${usedallas}", config.usedallas ? "checked" : "");
    buf.replace("${dallasres}", String(config.dallasres));
    buf.replace("${biasdallastemp}", String(config.biasDallasTemp));
    buf.replace("${dallaswait}", config.dallaswait ? "checked" : "");

    buf.replace("${usedht}", config.usedht ? "checked" : "");
    buf.replace("${dhttype}", String(config.dhttype));
    buf.replace("${biasdhttemp}", String(config.biasDHTTemp));
    buf.replace("${biasdhthumid}", String(config.biasDHTHumid));
    buf.replace("${dhthi}", config.dhthi ? "checked" : "");

    buf.replace("${battery}", config.battery ? "checked" : "");
    buf.replace("${battraw}", config.battraw ? "checked" : "");

    buf.replace("${dowifi}", config.dowifi ? "checked" : "");

    buf.replace("${doperf}", config.doperf ? "checked" : "");
    buf.replace("${perfraw}", config.perfraw ? "checked" : "");

    buf.replace("${deltat}", String(config.deltat));
    buf.replace("${pinblue}", String(config.pinblue));
    buf.replace("${invblue}", config.invblue ? "checked" : "");
    buf.replace("${pinconfig}", String(config.pinconfig));
    buf.replace("${pinpwrsens}", String(config.pinpwrsens));
    buf.replace("${pindallas}", String(config.pindallas));
    buf.replace("${pindhtdata}", String(config.pindhtdata));
    buf.replace("${adcmeas}", String(config.adcmeas));
    buf.replace("${battdiv}", String(config.battdiv));

    httpServer.send(200, "text/html", buf);
}

void webCSS() {
    httpServer.send(200, "text/css", css);
}

void getConfig() {
    // read config from EEPROM

    // check if the first byte is "magic" (i.e. EEPROM has been written before)
    if (EEPROM.read(0) == 0x42) {
        debugPrint("EEPROM magic byte 0x42 found.");
        // check version of config storage
        if (EEPROM.read(1) == config.cfgversion) {
            // read config
            EEPROM.get(1, config);

            // conversions

            // convert netmask "/25" -> "255.255.255.128"
            // [XXX] there must be an easier way to do this
            if (config.netmask < 8+1) {
                IPSubnet = { (uint8_t)(0xff - (0xff >> config.netmask)),
                    0, 0, 0};
            } else if (config.netmask < 16+1) {
                IPSubnet = { 0xff,
                    (uint8_t)(0xff - (0xff >> (config.netmask-8))), 0, 0};
            } else if (config.netmask < 24+1) {
                IPSubnet = { 0xff, 0xff,
                    (uint8_t)(0xff - ((uint8_t)0xff >> (config.netmask-16))), 0};
            } else {
                IPSubnet = { 0xff, 0xff, 0xff,
                    (uint8_t)(0xff - ((uint8_t)0xff >> (config.netmask-24)))};
            }

        } else {
            debugPrint("Ignoring EEPROM, wrong cfg version");
        }
    } else {
        // otherwise we rely on the defaults
        debugPrint("No config found, using hardcoded defaults.");
    }
}

void storeConfig() {
    String buf = "";

    debugPrint("Received form data");

    buf += (String)"Number of received args: " + httpServer.args() + "\n";
    for (int i = 0; i < httpServer.args(); i++) {
        buf += httpServer.argName(i) + ": " + httpServer.arg(i) + "\n";
    }

    if (httpServer.hasArg("ssid"))
        httpServer.arg("ssid").toCharArray(config.ssid, 32);

    if (httpServer.hasArg("password"))
        httpServer.arg("password").toCharArray(config.password, 32);

    if (httpServer.hasArg("ip"))
        config.ip = stringToIP(httpServer.arg("ip"));

    if (httpServer.hasArg("netmask"))
        config.netmask = httpServer.arg("netmask").toInt();

    if (httpServer.hasArg("gw"))
        config.gw = stringToIP(httpServer.arg("gw"));

    if (httpServer.hasArg("mqttip"))
        config.mqttip = stringToIP(httpServer.arg("mqttip"));

    if (httpServer.hasArg("mqttport"))
        config.mqttport = httpServer.arg("mqttport").toInt();

    if (httpServer.hasArg("usedallas"))
        config.usedallas = true;
    else
        config.usedallas = false;

    if (httpServer.hasArg("dallasres"))
        config.dallasres = httpServer.arg("dallasres").toInt();

    if (httpServer.hasArg("dallaswait"))
        config.dallaswait = true;
    else
        config.dallaswait = false;

    if (httpServer.hasArg("usedht"))
        config.usedht = true;
    else
        config.usedht = false;

    if (httpServer.hasArg("dhttype"))
        config.dhttype = httpServer.arg("dhttype").toInt();

    if (httpServer.hasArg("dhthi"))
        config.dhthi = true;
    else
        config.dhthi = false;

    if (httpServer.hasArg("battery"))
        config.battery = true;
    else
        config.battery = false;

    if (httpServer.hasArg("battraw"))
        config.battraw = true;
    else
        config.battraw = false;

    if (httpServer.hasArg("dowifi"))
        config.dowifi = true;
    else
        config.dowifi = false;

    if (httpServer.hasArg("doperf"))
        config.doperf = true;
    else
        config.doperf = false;

    if (httpServer.hasArg("perfraw"))
        config.perfraw = true;
    else
        config.perfraw = false;

    if (httpServer.hasArg("deltat"))
        config.deltat = httpServer.arg("deltat").toInt();

    if (httpServer.hasArg("pinblue"))
        config.pinblue = httpServer.arg("pinblue").toInt();

    if (httpServer.hasArg("invblue"))
        config.invblue = true;
    else
        config.invblue = false;

    if (httpServer.hasArg("pinconfig"))
        config.pinconfig = httpServer.arg("pinconfig").toInt();

    if (httpServer.hasArg("pinpwrsens"))
        config.pinpwrsens = httpServer.arg("pinpwrsens").toInt();

    if (httpServer.hasArg("pindallas"))
        config.pindallas = httpServer.arg("pindallas").toInt();

    if (httpServer.hasArg("pindhtdata"))
        config.pindhtdata = httpServer.arg("pindhtdata").toInt();

    if (httpServer.hasArg("adcmeas"))
        config.adcmeas = httpServer.arg("adcmeas").toInt();

    if (httpServer.hasArg("battdiv"))
        config.battdiv = httpServer.arg("battdiv").toFloat();

    debugPrint("Saving form data");
    EEPROM.put(0, 0x42);        // magic byte
    EEPROM.put(1, config);
    EEPROM.commit();            // ESP8266 EEPROM library needs this

    httpServer.send(200, "text/plain", buf);
}


void debugPrint(String msg) {
    #ifdef SERIALDEBUG
    Serial.println(msg);
    #endif
}

// vim: sw=4:expandtab:ts=4:tw=80

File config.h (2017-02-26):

/*
    CONFIGURATION
 */

// behaviour/timing
const byte sleepWifiCheck = 50;     // ms to sleep between checks if associated
const byte maxConnRetry = 200;      // how many sleepWifiCheck sleeps
const unsigned int noConnSleepSec = 600;
const unsigned int lowBattSleepSec = 3600;
const byte sleepEnd = 100;          // ms to sleep before going to deepSleep
const byte sleepADCmeasure = 2;   // ms to sleep before each ADC read
const unsigned int sleepDHT = 2000; // ms to sleep before querying DHT
const byte maxSensors = 16;

// #define SERIALDEBUG

// hardware
const float Vdd = 3.3;
const float Voff = 0.00;        // highest V where ADC still reports "0"
const float VLowBat = 3.0;      // don't take/send measurements if Vbat < this

// Dallas
/* Each DS18B20 has its own ID, but as the rest of the software can't handle
 * more than 1 Dallas (yet), we can just stick to a hardcoded Id. Set to 0
 * to use the actual ID */
const unsigned int DALLAS_ID = 0x1820;

// Webserver
const char indexPage[] =
R"(<!DOCTYPE html>
<html>
    <head>
        <title>ESP_BaPoTeSta Maintenance</title>
        <link href="style.css" rel="stylesheet" />
        <meta name="viewport" content="width=device-width, initial-scale=1" />
    </head>
    <body>
        <h1>ESP_BaPoTeSta Maintenance</h1>
        <h2>Configuration</h2>
        <form method="POST" action="/config" enctype="multipart/form-data"  class="pure-form pure-form-aligned">
            <fieldset>
                <legend>Network</legend>
                <div class="inputgroup">
                    <label for="ssid">ssid</label><input type="text" id="ssid" name="ssid" value="${ssid}" />
                    <label for="password">password</label><input type="text" id="password" name="password" placeholder="0 or 8+ chars" value="${password}" />
                    <label for="ip">IP</label><input type="text" id="ip" name="ip" value="${ip}" pattern="\d\d?\d?.\d\d?\d?.\d\d?\d?.\d\d?\d?" />
                    <label for="netmask">Netmask</label><input type="number" min="0" max="31" id="netmask" name="netmask" value="${netmask}" />
                    <label for="gw">Gateway</label><input type="text" pattern="\d\d?\d?.\d\d?\d?.\d\d?\d?.\d\d?\d?" id="gw" name="gw" value="${gw}" />
                </div>
                <div class="inputgroup">
                    <label for="mqttip">MQTT IP</label><input type="text" pattern="\d\d?\d?.\d\d?\d?.\d\d?\d?.\d\d?\d?" id="mqttip" name="mqttip" value="${mqttip}" />
                    <label for="mqttport">MQTT Port</label><input type="number" min="1" max="65535" id="mqttport" name="mqttport" value="${mqttport}" />
                </div>
            </fieldset>
            <fieldset>
                <legend>Measuring</legend>
                <div class="inputgroup">
                    <label for="usedallas">Use DS18B20</label><input type="checkbox" id="usedallas" name="usedallas" ${usedallas} />
                    <label for="dallasres"> resolution</label><input type="number" min="9" max="12" id="dallasres" name="dallasres" value="${dallasres}" />
                    <label for="biasdallastemp"> bias</label><input type="number" min="-1.0" max="1.0" step="0.01" id="biasdallastemp" name="biasdallastemp" value="${biasdallastemp}" />
                    <label for="dallaswait"> check for result</label><input type="checkbox" id="dallaswait" name="dallaswait" ${dallaswait} />
                </div>
                <div class="inputgroup">
                    <label for="usedht">Use DHT</label><input type="checkbox" id="usedht" name="usedht" ${usedht} />
                    <label for="dhttype"> type</label><input type="number" min="11" max="33" id="dhttype" name="dhttype" value="${dhttype}" />
                    <label for="biasdhttemp"> temp bias</label><input type="number" min="-1.0" max="1.0" step="0.01" id="biasdhttemp" name="biasdhttemp" value="${biasdhttemp}" />
                    <label for="biasdhthumid"> hum bias</label><input type="number" min="-10" max="10" step="0.01" id="biasdhthumid" name="biasdhthumid" value="${biasdhthumid}" />
                    <label for="dhthi"> report HI</label><input type="checkbox" id="dhthi" name="dhthi" ${dhthi} />
                </div>
                <div class="inputgroup">
                    <label for="battery">Report battery</label><input type="checkbox" id="battery" name="battery" ${battery} />
                    <label for="battraw"> incl. raw value</label><input type="checkbox" id="battraw" name="battraw" ${battraw} />
                </div>
                <div class="inputgroup">
                    <label for="dowifi">Report WiFi strength</label><input type="checkbox" id="dowifi" name="dowifi" ${dowifi} />
                </div>
                <div class="inputgroup">
                    <label for="doperf">Report performance</label><input type="checkbox" id="doperf" name="doperf" ${doperf} />
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

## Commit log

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2015-11-06 BUG: SLEEPSEC was off by factor 10
    [ESP_BaPoTeSta.ino]
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2015-11-06 ENH: use static IP address
    DHCP just takes too long
    [ESP_BaPoTeSta.ino]
2015-11-06 ENH: don't recalibrate WiFi after wakeup
    this should be the best deepsleep-mode, if I understood
    http://www.esp8266.com/wiki/doku.php?id=esp8266_power_usage&s[]=deepsleep#system_deep_sleep_set_option
    correctly
    [ESP_BaPoTeSta.ino]
2015-11-06 BUG: wrong var name IPGW i.of IPGateway
    [ESP_BaPoTeSta.ino]
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2015-11-26 CFG: specified wrong Rfix
    [ESP_BaPoTeSta.ino]
2015-11-26 BUG: printf can't do %f on Arduino
    but we luckily don't need that anyway
    [ESP_BaPoTeSta.ino]
2015-11-26 ENH: Correctly calculate temperature
    Formula: https://en.wikipedia.org/wiki/Thermistor#B_or_.CE.B2_parameter_equation
    Values for my thermistor (MF52-103/3950) taken from datasheet
    (doubled R0, as I'm using 2 of those in series)
    [ESP_BaPoTeSta.ino]
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2015-11-26 CFG: simple fix for inaccurate measurements
    dunno why my ADC reports too /big/ values instead of too low.
    But tested with multimeter: 0.645V got reported as "670", 670/1024 = 0.655
    [ESP_BaPoTeSta.ino]
2015-11-26 TXT: My thermistor is an NTC, not PTC
    fix variable names and comments
    [ESP_BaPoTeSta.ino]
2015-11-26 BUG: Need to define function prototypes
    otherwise we trigger a bug in Arduino 1.6.6 and the newest ESP8266 code
    [ESP_BaPoTeSta.ino]
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2015-11-29 BUG: printed temp was only padded to 3 digits
    The sign (+/-) also counts towards printf's field width, so we
    need to use width 5, not just 4
    [ESP_BaPoTeSta.ino]
2015-11-29 BUG: switch off blue LED for no-WiFi-sleep
    move "switch off blue LED + deepSleep" to dedicated function
    [ESP_BaPoTeSta.ino]
2015-11-29 BUG: must not report temps if ADC out-of-range
    could happen if Rfix and/or temperature is too high
    for my setup (Rfix=4.7k, 20k NTC) this happens around 45degC
    [ESP_BaPoTeSta.ino]
2015-11-29 BUG: use int instead of byte for SLEEPSEC
    especially important since we are sleeping 299s now :)
    [ESP_BaPoTeSta.ino]
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2015-12-05 GIT: add KiCAD files
    [ESP_BaPoTeSta.kicad_pcb, ESP_BaPoTeSta.sch]
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2015-12-05 TXT: moved "TODO" stuff to github Issues
    [ESP_BaPoTeSta.ino]
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2015-12-06 TXT: "1u" -> ">=1u"
    as bigger caps are also okay
    [ESP_BaPoTeSta.kicad_pcb, ESP_BaPoTeSta.sch]
2015-12-06 TXT: fine-tune silk-screen
    move labels, put most "Values" in F.SilkS, add some pin labels.
    fixes #5, fixes #8
    [ESP_BaPoTeSta.kicad_pcb]
2015-12-06 TXT: label all ESP pins
    [ESP_BaPoTeSta.kicad_pcb]
2015-12-06 TXT: fix orientation of front-side label
    so it's the same direction as all other labels
    [ESP_BaPoTeSta.kicad_pcb]
2015-12-06 TXT: add github-URL to label
    [ESP_BaPoTeSta.kicad_pcb]
2015-12-06 TXT: add voltage range to battery header
    [ESP_BaPoTeSta.kicad_pcb]
2015-12-06 TXT: fix "fat" text labels
    [ESP_BaPoTeSta.kicad_pcb]
2015-12-06 ENH: Make board more compact
    by moving the battery header. Now only 40x50mm (was 50x50mm)
    [ESP_BaPoTeSta.kicad_pcb]
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2015-12-06 TXT: add BOM
    fixes #8
2015-12-06 TXT: fix BOM table layout
2015-12-07 TXT: add silk-screen rect for Sensor ID
    so I can write some number on each sensor board
    [ESP_BaPoTeSta.kicad_pcb]
2015-12-07 TXT: add ESP pin labels on back too
    see commit:d7dbb19
    [ESP_BaPoTeSta.kicad_pcb]
2015-12-07 ENH: add Power header
    might be useful
    [ESP_BaPoTeSta.kicad_pcb, ESP_BaPoTeSta.sch]
2015-12-07 TXT: improve labeling of MCP1700
    drop "/TO" from name, so it fits better on the silk-screen
    uppercase "IN" and "OUT" (as everything else is uppercase)
    [ESP_BaPoTeSta.kicad_pcb, ESP_BaPoTeSta.sch]
2015-12-07 ENH: consistently use rectangular pads for GND
    [ESP_BaPoTeSta.kicad_pcb]
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2015-12-07 ENH: bigger SensorID field on F.SilkS
    by moving the 1st mounting hole NW
    [ESP_BaPoTeSta.kicad_pcb]
2015-12-07 ENH: Move buttons closer to the edge of the PCB
    [ESP_BaPoTeSta.kicad_pcb]
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2015-12-12 BUG: 1Wire-pin was hardcoded and wrong
    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
    [ESP_BaPoTeSta.ino, config.h]
2015-12-12 SRC: make all delays configurable
    fixes #12
    [ESP_BaPoTeSta.ino, config.h]
2015-12-12 BUG: generated JSON wasn't correct JSON
    can't use hex-values or trailing commas
    [ESP_BaPoTeSta.ino]
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2015-12-12 ENH: Measure battery level
    fixes #9
    [ESP_BaPoTeSta.h, ESP_BaPoTeSta.ino, config.h]
2015-12-13 BUG: fix invalid JSON
    forgot to increase pointer. I hate C.
    [ESP_BaPoTeSta.ino]
2015-12-13 BUG: measurements need to end up as integer
    so we can easily put them into JSON
    (Arduino sprintf can't do %f)
    [ESP_BaPoTeSta.h, ESP_BaPoTeSta.ino]
2015-12-13 BUG: spurious comma in JSON
    forgot the "if"
    [ESP_BaPoTeSta.ino]
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2015-12-13 ENH: support buggy DS18B20
    My DS18B20 says it's finished converting, when it's really not.
    It thus will return 85degC instead of the real temp.
    [ESP_BaPoTeSta.ino, config.h]
2016-01-01 BUG: need to call PubSub loop()
    necessary according to the docs :)
    [ESP_BaPoTeSta.ino]
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2016-01-01 BUG: forgot to actually connect to to MQTT-broker
    [ESP_BaPoTeSta.ino]
2016-01-01 BUG: MQTT needs other port
    [config.h]
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2016-01-05 BUG: Need to power sensors before init'ing them
    [ESP_BaPoTeSta.ino]
2016-01-05 ENH: support DHT sensors
    fixes #13
    [ESP_BaPoTeSta.h, ESP_BaPoTeSta.ino, config.h]
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2016-01-07 BUG: Forgot to measure battery voltage
    [ESP_BaPoTeSta.ino]
2016-01-07 SRC: use "long" format for chipId-sprintf
    gcc complained (correctly)
    [ESP_BaPoTeSta.ino]
2016-01-07 BUG: Used non-defined PIN_XXX_POWER
    those are consts, not defines, so the code never got compiled
    [ESP_BaPoTeSta.ino]
2016-01-07 BUG: Forgot to actually measure DHT
    [ESP_BaPoTeSta.ino]
2016-01-07 SRC: use parenthesis around shift-left
    gcc complained that this might be wrong otherwise
    [ESP_BaPoTeSta.ino]
2016-01-07 BUG: battery "divider" constant was 0
    need to do float division
    [config.h]
2016-01-07 WIP: Redesign PCB
    Use SMD resistors, and start to work on #14, #15 and #16
    [ESP_BaPoTeSta.kicad_pcb, ESP_BaPoTeSta.sch]
2016-01-07 WIP: Continue improving PCB
    continue the work started in 0493dcc
    add additional header to enter config mode
    [ESP_BaPoTeSta.kicad_pcb, ESP_BaPoTeSta.sch]
2016-01-09 ENH: Improve PCB
    Finalize work started in 0493dcc and 57554c2
    Add DHT22 (you can now install 2 sensors, DHT22 and DS18B20)
    Fix the various bugs (fixes #14, fixes #15, fixes #16)
    Avoid ground-fill at DS18B20 GND pin (improves accuracy)
    Drop the 2 push-buttons
    Board now much smaller (3x5cm)
    [ESP_BaPoTeSta.kicad_pcb, ESP_BaPoTeSta.sch]
2016-01-10 ENH: use small ceramic buffer caps
    lower ESR. Still use one additional big electrolytic cap
    [ESP_BaPoTeSta.kicad_pcb, ESP_BaPoTeSta.sch]
2016-01-10 ENH: [pcb] grid-align battery header
    and minor improvements to tracks
    add a via between the ground planes under the ESP
    [ESP_BaPoTeSta.kicad_pcb]
2016-01-10 ENH: [pcb] add strain relief for battery cable
    and change type of 3mm-mounting-hole from "1pin" to "MountingHole"
    [ESP_BaPoTeSta.kicad_pcb]
2016-01-10 ENH: replace 4k7 resistor by 2 10k
    so I don't have to buy 4k7 resistors
    Enlarge ground plane beneath ESP
    [ESP_BaPoTeSta.kicad_pcb, ESP_BaPoTeSta.sch]
2016-01-10 ENH: improve battery measurement accuracy
    use 56k instead of 68k resistor
    This will work up to 6.6V -- more than enough, as max
    rated input voltage of the MCP1700 is only 6V
    [ESP_BaPoTeSta.sch]
2016-01-10 TXT: add label to bottom silk-screen
    and move "SensorID" field a little bit
    [ESP_BaPoTeSta.kicad_pcb]
2016-01-10 TXT: [pcb] label ESP pin usage, etc
    label the 3 areas (Programming, PSU, Sensors)
    align ESP pin labels
    hide some "Fab" text
    [ESP_BaPoTeSta.kicad_pcb]
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2016-01-11 ENH: [pcb] add measurement point at GPIO4
    The only unused pin, can now be used for custom hacks
    [ESP_BaPoTeSta.kicad_pcb]
2016-01-12 ENH: [pcb] add SMD jumpers for data lines
    makes it easier to re-use unused lines as GPIO
    [ESP_BaPoTeSta.kicad_pcb, ESP_BaPoTeSta.sch]
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2016-01-12 GIT: missed a line at last merge 59a1d02
    [ESP_BaPoTeSta.kicad_pcb]
2016-01-12 GIT: Finish merge 59a1d02
    add the custom pin to the schematic, link the measurement-pin in the PCB
    [ESP_BaPoTeSta.kicad_pcb]
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2016-01-14 ENH: [pcb] minor silkscreen fixes
    also, finish f41bc1a
    [ESP_BaPoTeSta.kicad_pcb, ESP_BaPoTeSta.sch]
2016-01-14 ENH: [pcb] move PwrSens track a little
    [ESP_BaPoTeSta.kicad_pcb]
2016-01-17 SRC: fix compiler warning re char<->const char
    [ESP_BaPoTeSta.h, ESP_BaPoTeSta.ino]
2016-01-17 BUG: webserver crashed
    Switched from char* to Arduino's own "String", now everything works
    [ESP_BaPoTeSta.ino, config.h]
2016-01-17 BUG: forgot a "<" in HTML
    [config.h]
2016-01-17 TXT: Improve HTML form
    set correct types and ranges
    make all texts "labels"
    add "Revert" button
    [config.h]
2016-01-18 BUG: DS18B20 resolution is 9..12, not 10..13
    [config.h]
2016-01-24 BUG: use config.dhttype
    instead of DHT_TYPE, or just dhttype
    [ESP_BaPoTeSta.ino]
2016-01-27 BUG: need to prototype storeConfig()
    [ESP_BaPoTeSta.h]
2016-01-28 BUG: IP parsing error
    accidentally increased i twice
    [ESP_BaPoTeSta.ino]
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2016-02-04 BUG: html-form didn't support "-1" for blue-LED-pin
    "-1" means "don't light blue LED"
    [config.h]
2016-02-04 BUG: html form didn't work since da37339
    accidentally dropped the "name" attributes from the form fields
    [config.h]
2016-03-26 SRC: useless template operation
    replacing "{ssid}" with the SSID /twice/ doesn't make sense
    [ESP_BaPoTeSta.ino]
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2016-04-20 CFG: better defaults for v0.5
    The ESP-12E I'm using has pins 4 and 5 swapped, and the blue
    LED seems to be connected in some unusual way
    [ESP_BaPoTeSta.h]
2016-04-20 ENH: sanity check temp/humidity values
    compare measured values with possible range of the sensors
    fixes #28
    [ESP_BaPoTeSta.ino]
2016-04-20 BUG: HTML form validation for bias values too strict
    [config.h]
2016-05-08 ENH: don't measure/send if Vbatt too low
    to avoid bogus data
    [ESP_BaPoTeSta.ino, config.h]
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2016-06-11 ENH: started work on new board layout
    [ESP_BaPoTeSta.sch]
2016-06-13 ENH: Redesigned schematic
    now with 4 I2C, 2 1Wire and 1 DHT port.
    Also added MOSFET for battery measurement,
    and power-saving Schottky for GPIO16 -- thanks Malte!
    [ESP_BaPoTeSta.sch]
2016-06-17 ENH: Started work on PCB
    [ESP_BaPoTeSta.kicad_pcb, ESP_BaPoTeSta.sch]
2016-06-21 WIP: continue work on new board
    remove diode, more/better labels,...
    [ESP_BaPoTeSta.kicad_pcb, ESP_BaPoTeSta.sch]
2016-06-21 BUG: Don't send "2147483647"
    The DHT lib returns NaN when sth went wrong; this didn't get
    caught by the comparison, so now check using isnan()
    see #28
    [ESP_BaPoTeSta.ino]
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2016-06-21 BUG: don't call dhtSensor.begin() when usedht is false
    looks like my brain was in Python-mode...
    [ESP_BaPoTeSta.ino]
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2016-06-22 CFG: set correct height for my BMP280
    [ESP_BaPoTeSta.h]
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2016-11-08 SRC: PCB: cleanup KiCAD library paths
    not using open-project parts anymore
    use kicad-ESP8266 from the submodule
    [ESP_BaPoTeSta.sch]
2016-11-08 TXT: PCB: fix description of ESP
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2016-11-08 ENH: PCB: cosmetic changes
    label "RST" net
    label pins of DHT header
    [ESP_BaPoTeSta.kicad_pcb, ESP_BaPoTeSta.sch]
2016-11-08 ENH: PCB: add mounting holes
    [ESP_BaPoTeSta.kicad_pcb]
2016-11-08 TXT: PCB: fix "Sensor ID" position
    [ESP_BaPoTeSta.kicad_pcb]
2016-11-08 TXT: PCB: some more cosmetics
    move labels around a bit
    [ESP_BaPoTeSta.kicad_pcb]
2016-11-08 ENH: PCB: use SOT-23 MCP1700
    takes less space, easier to solder
    obsoletes #21
    [ESP_BaPoTeSta.kicad_pcb, ESP_BaPoTeSta.sch]
2016-11-09 ENH: PCB: minor cosmetical changes
    move left mounting hole
    move el.cap
    lines for pin labels at headers
    [ESP_BaPoTeSta.kicad_pcb]
2016-11-09 WIP: PCB: started routing sensors
    [ESP_BaPoTeSta.kicad_pcb]
2016-11-09 WIP: PCB: continued routing
    [ESP_BaPoTeSta.kicad_pcb]
2016-11-14 WIP: PCB: battery charger
    [ESP_BaPoTeSta.kicad_pcb, ESP_BaPoTeSta.sch]
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2016-11-14 WIP: PCB: redesign nearly finished
    [ESP_BaPoTeSta.kicad_pcb, ESP_BaPoTeSta.sch]
2016-11-29 DOC: PCB: silkscreen improvements
    Fix size/position of labels
    swap GPIO 4<->5 labels
    add header diagram
    fix voltage labels (ESP needs 2.5V in, so 3.0V battery is ok)
    [ESP_BaPoTeSta.kicad_pcb, ESP_BaPoTeSta.sch]
2016-11-29 ENH: PCB: fix last 90deg-trace-bend
    fixes #29
    [ESP_BaPoTeSta.kicad_pcb]
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2016-11-30 ENH: Use SMD capacitor as C2
    fixes #24
    fixes #30
    [ESP_BaPoTeSta.kicad_pcb, ESP_BaPoTeSta.sch]
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2016-12-03 ENH: PCB: Prevent undervoltage
    If the undervoltage-sensor NCP300 senses too low a battery voltage,
    it will tie its output to GND, thus switching off the BSS806N
    [ESP_BaPoTeSta.kicad_pcb, ESP_BaPoTeSta.sch]
2016-12-03 ENH: CFG: Increase sleep time on low battery voltage
    Another minor measure to prevent deep discharge of the battery
    [config.h]
2016-12-03 ENH: PCB: Thermal relief for SMD GND pads
    fixes #22
    [ESP_BaPoTeSta.kicad_pcb]
2016-12-03 DOC: SCH: Improve schematic layout
    Join battery charger and voltage regulation parts
    Move parts around
    Fix Rev/Date
    [ESP_BaPoTeSta.sch]
2016-12-04 ENH: PCB: Most traces are now 0.5mm
    0.5mm (20mill) are more than enough for the low currents (500mA)
    Only the "main" trace (USB+ to MCP73831 to battery to MCP1700 to ESP)
    is still 1mm (40mill).
    GND is transferred via the copper planes.
    fixes #31
    [ESP_BaPoTeSta.kicad_pcb]
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2016-12-04 WIP: PCB: Route ATmega
    and add some test points
    [ESP_BaPoTeSta.kicad_pcb, ESP_BaPoTeSta.sch]
2016-12-04 DOC: PCB: Add LED documentation
    Label pins of connector-legend
    Move mounting hole a bit, to make sure the screw won't touch anything
    [ESP_BaPoTeSta.kicad_pcb]
2016-12-04 ENH: PCB: Make it easier to attach a 433 sender
    Add solder pads for GND and SMD, and move the pads for PB5 and PC1 to
    the border of the board
    see #34
    [ESP_BaPoTeSta.kicad_pcb, ESP_BaPoTeSta.sch]
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2016-12-05 CFG: PCB: Use 500mA charging current
    not just 455mA
    [ESP_BaPoTeSta.sch]
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2016-12-05 BUG: PCB: accidentally deleted pin labels on B.SilkS
    happened when rotating the ATmega for commit 8d62ca9
    [ESP_BaPoTeSta.kicad_pcb]
2016-12-05 ENH: PCB: Minor cosmetic fixes
    remove a remaining "no_connect" (between 2 GND pins of ATmega)
    hide "TEST_1P" labels
    remove "blk" label which was below a pin header
    remove some useless traces
    [ESP_BaPoTeSta.kicad_pcb]
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2017-01-05 ENH: pcb: minor cosmetic enhancements
    remove rectangle in SOT23-5 parts
    replace tiny LED symbol with cathode-marker for 1206 LEDs
    remove tiny "TPx" labels
    move some labels
    label C2 as "0m1" instead of "100u" so it's readable on PCB
    make "LED off" symbols darker by removing copper fill
    increase textsize of "ATmega" label by rotating it by 45degC
    other minor stuff
    [ESP_BaPoTeSta.kicad_pcb, ESP_BaPoTeSta.sch]
2017-01-05 ENH: PCB: provide access to ISP pins of ATmega
    fixes #38
    [ESP_BaPoTeSta.kicad_pcb, ESP_BaPoTeSta.sch]
2017-01-05 ENH: PCB: improve PD3/PD4 pads
    align on 100mill raster, add a GND pad
    [ESP_BaPoTeSta.kicad_pcb]
2017-02-19 ENH: fw: send WiFi strength
    fixes #42
    [ESP_BaPoTeSta.h, ESP_BaPoTeSta.ino, config.h]
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2017-02-26 BUG: [fw] Workaround for #43
    Pull PwrSens LOW right before measuring the battery voltage
    On my prototype, replaced C4 (0.1uF) with 4.7uF, which allows for
    ~50ms of measuring; set sleepADCmeasure to 2(ms), so we are done in
    ~10ms.
    The source looks a bit ugly now, need to rethink this; definitely when
    using the AVR, as setup() won't be called at each run anymore
    [ESP_BaPoTeSta.ino, config.h]
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

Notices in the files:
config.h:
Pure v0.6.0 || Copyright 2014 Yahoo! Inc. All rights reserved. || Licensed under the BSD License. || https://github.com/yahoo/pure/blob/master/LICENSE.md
